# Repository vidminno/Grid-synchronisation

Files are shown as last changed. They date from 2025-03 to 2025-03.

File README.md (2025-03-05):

# Grid synchronisation

This repository contains an easy-to-implement grid synchronisation circuit.

## Content
- **Hardware**: KiCad schematic and layout design for isolated grid frequency acquisition.
- **Software**: Implementation for an STM32 Nucleo H755 for grid synchronisation.

## Functionality
The circuit uses opto-emulators (ISOM8710) for isolated detection of the mains zero crossing. A microcontroller analyses the signal edges to calculate the mains frequency and phase position.

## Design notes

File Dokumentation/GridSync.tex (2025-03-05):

\documentclass[a4paper,12pt]{article}

% Packages
\usepackage[utf8]{inputenc}  % Special characters
\usepackage{amsmath, amssymb} % Mathematical symbols
\usepackage{graphicx} % Including graphics
\usepackage{caption} % Captions for figures
\usepackage{geometry} % Adjusting page margins
\geometry{a4paper, left=2.5cm, right=2.5cm, top=2.5cm, bottom=2.5cm}

\begin{document}
    
    \title{Grid Synchronisation}
    \author{Simon Peter}
    \date{\today}
    \maketitle
    
\begin{abstract}
Dieses Repository enthält eine einfach zu implementierende Grid-Synchronisationsschaltung.
\end{abstract}

\section{Einleitung}
Das Repository enthält die Hardware, bestehend aus einem KiCad-Schaltplan und einem zugehörigen Layoutentwurf. Außerdem ist die Software für einen STM32 Nucleo H755 enthalten.

\section{Hardware}
Nachfolgend wird eine Schaltung vorgestellt, mit der die Netzfrequenz isoliert abgegriffen und der aktuelle Netzzeitpunkt softwareseitig ermittelt werden kann. Die Schaltung besteht aus zwei Komparatoren, welche die Höhe der Netzspannung vergleichen und so auf den Nulldurchgang schließen. Nachteilig an Komparatoren ist die Notwendigkeit einer Spannungsversorgung. Deshalb werden Opto-Emulatoren vom Typ ISOM8710 verwendet, die sich ähnlich wie Optokoppler verhalten. Opto-Emulatoren haben gegenüber Optokopplern jedoch verbesserte Parameter, wie beispielsweise eine höhere Störfestigkeit gegenüber schnellen Gleichtaktspannungen (engl. \textit{High Common Mode Transient Immunity} CMTI).

\begin{figure}[htb]
    \footnotesize
    \centering
    
    \caption{Isolierte Erfassung des Netznulldurchgangs um die Netzfrequenz sowie softwareseitig den Netzzeitpunk zu ermitteln.}	
    \label{fig:HwGridSync}
\end{figure}

Der erste Opto-Emulator (Abbildung~\ref{fig:HwGridSync} oben) soll schalten, wenn in der positiven Halbwelle die Eingangsspannung $u_\text{in}$ ausreichend hoch ist. In der anderen Halbwelle darf er nicht schalten. Mit einer Z-Diode wird diese Eingangsspannung gebildet. Wird die Z-Diode in Sperrrichtung betrieben, liegt die Zenerspannung ($6,2~\text{V}$) an. In der Halbwelle mit entgegengesetzter Polarität befindet sich die Z-Diode in Durchlassrichtung, weshalb die Eingangsspannung zu gering ist. Somit schaltet der Opto-Emulator kurz nach dem Nulldurchgang zur positiven Halbwelle ein und vor dem Nulldurchgang zur negativen Halbwelle aus. Zu beachten ist, dass der Ausgang des ISOM8710 negiert ist. Der Ausgang ist also im Ruhezustand $1$ ($3,3~\text{V}$).

Die beschriebene Schaltung ist doppelt ausgeführt, wobei die zweite Schaltung die Netzspannung entgegengesetzt aufnimmt. Abbildung~\ref{fig:InGridSync} veranschaulicht die beschriebenen Signalverläufe. Der Mikrocontroller kann die Flanken auswerten, hieraus den Nulldurchgang rekonstruieren und somit die Netzfrequenz berechnen. Durch einen internen Takt können zudem jederzeit die aktuellen Winkelverhältnisse des Netzes rekonstruiert werden.

Im Folgenden wird die Schaltung dimensioniert. Es wird ein minimaler Eingangsstrom von $i_\text{in} = 2,5~\text{mA}$ gewählt, der geringfügig über dem empfohlenen minimalen Eingangsstrom von $2~\text{mA}$ liegt. Die Eingangsspannung beträgt hierbei $u_\text{in} = 1,5~\text{V}$. Der minimale Rückwärtsstrom der Z-Diode ist auf $i_\text{D} = 1~\text{mA}$ festgelegt, wobei die Zenerspannung hierbei $u_\text{D} = 6,2~\text{V}$ beträgt. Die minimale netzseitige Eingangsspannung wird auf $U_\text{AC1} = 40~\text{V}$ gesetzt. Mithilfe der Gleichungen~\ref{eq:IsoR1} und~\ref{eq:IsoR2} können nun die erforderlichen Widerstände berechnet werden. Der Kondensator in der Schaltung dient zur Unterdrückung von Störungen.

\begin{align}
    R_1 &= \frac{\widehat{u}_\text{AC12} \cdot \sqrt{2} - u_\text{D}}{i_\text{in} + i_\text{D}} = \frac{40~\text{V} \cdot \sqrt{3} \cdot \sqrt{2} - 6,2~\text{V}}{2,5~\text{mA} + 1~\text{mA}} = 26,22~\text{k}\Omega
    \label{eq:IsoR1} \\
    R_2 &= \frac{u_\text{D} - u_\text{in}}{i_\text{in}} = \frac{6,2~\text{V} - 1,5~\text{V}}{2,5~\text{mA}} = 1,88~\text{k}\Omega
    \label{eq:IsoR2}
\end{align}

\section{Software}
\label{sec:SwGridFrequency}
Zur Bestimmung der Netzfrequenz und der aktuellen Phasenlage muss der Mikrocontroller die Signalflanken von $u_\text{S12\{L,H\}}$ auswerten und in Relation zu einem internen Takt setzen. Wie Abbildung~\ref{fig:InGridSync} zeigt, finden Nulldurchgänge zwischen folgenden Flanken statt.
\begin{itemize}
    \item Nulldurchgang der Eingangsspannung in Richtung der positiven Polarität:\\
    $-$ Positive Flanke von $u_\text{S12L}$ gefolgt von negativer Flanke von $u_\text{S12H}$
    \item Nulldurchgang der Eingangsspannung in Richtung der negativen Polarität:\\
    $-$ Positive Flanke von $u_\text{S12H}$ gefolgt von negativer Flanke von $u_\text{S12L}$
\end{itemize}

Die Detektion der Flanken erfolgt über die Input-Capture-Einheit eines Timers des Mikrocontrollers. Der Timer zählt in der Betriebsart Upcounting. Die Input-Capture-Einheit ermöglicht bei externen Signalflanken die Zwischenspeicherung des aktuellen Timer-Wertes. Beide Signalleitungen triggern jeweils einen Kanal der Input-Capture-Einheit.

\section{Inbetriebnahme}
In diesem Kapitel werden die Signalverläufe der Phasenerkennungsschaltung und die Betriebseigenschaften anhand der Abbildung~\ref{fig:InGridSync} erläutert. Obwohl die Schaltung für $U_\text{AC1} = 40~\text{V}$ dimensioniert wurde, funktioniert sie bereits bei etwa $U_\text{AC1} = 12~\text{V}$. Ohne Anpassung des Vorwiderstandes der Z-Diode wird somit ein großer Spannungsbereich abgedeckt. Die Schaltung ist zwischen $\text{L1}$ und $\text{L2}$ angeschlossen, softwareseitig können daraus jedoch sämtliche Winkelbeziehungen (z.B. zwischen $\text{L1}$ und $\text{N}$) berechnet werden. $u_\text{12\{L,H\}}$ sind die Ausgangssignale der Opto-Emulatoren, welche vom Mikrocontroller für die Nulldurchgangsrekonstruktion ausgewertet werden. $u_\text{t}$ ist ein Testausgangspin des Mikrocontrollers zur Überprüfung der Phasenerkennung. Er wird während der positiven Halbwelle auf $1$ und bei der negativen Halbwelle auf $0$ geschaltet. 

Aufgrund der Hysterese der Opto-Emulatoren stellt sich ein konstanter Winkelfehler von $5$ Grad ein. Dies ist in Abbildung~\ref{fig:InGridSync} ersichtlich, da die steigende Flanke von  $u_\text{12L}$ sowie die fallende Flanke von $u_\text{12H}$ nicht symmetrisch um den Zeitpunkt $t~=~0$ liegen. Dies wird softwareseitig kompensiert, wodurch der Winkelfehler auf unter $1$ Grad verbessert wird. Dies sind in Anbetracht des einfachen Schaltungsaufbaus gute Ergebnisse.

\begin{figure}[ht]
    \footnotesize
    \centering
    
    \caption{Signalverläufe der Phasenerkennungsschaltung bei $f~=~55~\text{Hz}$. Durch die Auswertung der Ausgangssignale $u_\text{12\{L,H\}}$ der Opto-Emulatoren kann der Mikrocontroller den Nulldurchgang exakt vorhersagen (siehe Testausgangssignal $u_\text{t}$).}	
    \label{fig:InGridSync}
\end{figure}

\end{document}

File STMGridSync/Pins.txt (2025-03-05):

---------------------------------------------------------------------
Pin-Belegung
---------------------------------------------------------------------
Pin  |  Funktion  | Status | Beschreibung
---------------------------------------------------------------------

PB0     Nucleo LD1  Use
PE1     Nucleo LD2  Use
PB14    Nucleo LD3  Use
PC13    Nucleo BTN  Use

PE5     TIM15_CH1   Use      Input capture (5V tolerant)
PE6     TIM15_CH2   Use      Input capture (5V tolerant)

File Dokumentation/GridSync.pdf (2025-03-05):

## Grid Synchronisation

### Simon Peter

### March 5, 2025

Abstract

Dieses Repository enthält eine einfach zu implementierende Grid-Synchronisationsschaltung.

### 1 Einleitung

Das Repository enthält die Hardware, bestehend aus einem KiCad-Schaltplan und einem zugehörigen Layoutentwurf. Außerdem ist die Software für einen STM32 Nucleo H755 enthalten.

### 2 Hardware

Nachfolgend wird eine Schaltung vorgestellt, mit der die Netzfrequenz isoliert abgegriffen und der aktuelle Netzzeitpunkt softwareseitig ermittelt werden kann. Die Schaltung besteht aus zwei Komparatoren, welche die Höhe der Netzspannung vergleichen und so auf den Nulldurchgang schließen. Nachteilig an Komparatoren ist die Notwendigkeit einer Spannungsversorgung. Deshalb werden Opto-Emulatoren vom Typ ISOM8710 verwendet, die sich ähnlich wie Optokoppler verhalten. Opto-Emulatoren haben gegenüber Optokopplern jedoch verbesserte Parameter, wie beispielsweise eine höhere Störfestigkeit gegenüber schnellen Gleichtaktspannungen (engl. High Common Mode Transient Immunity CMTI).
Der erste Opto-Emulator (Abbildung 1 oben) soll schalten, wenn in der positiven Halbwelle die Eingangsspannung uin ausreichend hoch ist. In der anderen Halbwelle darf er nicht schalten. Mit einer Z-Diode wird diese Eingangsspannung gebildet. Wird die Z-Diode in Sperrrichtung betrieben, liegt die Zenerspannung (6, 2 V) an. In der Halbwelle mit entgegengesetzter Polarität befindet sich die Z-Diode in Durchlassrichtung, weshalb die Eingangsspannung zu gering ist. Somit schaltet der Opto-Emulator kurz nach dem Nulldurchgang zur positiven Halbwelle ein und vor dem Nulldurchgang zur negativen Halbwelle aus. Zu beachten ist, dass der Ausgang des ISOM8710 negiert ist. Der Ausgang ist also im Ruhezustand 1 (3, 3 V).
Die beschriebene Schaltung ist doppelt ausgeführt, wobei die zweite Schaltung die Netzspannung entgegengesetzt aufnimmt. Abbildung 2 veranschaulicht die beschriebenen Signalverläufe. Der Mikrocontroller kann die Flanken auswerten, hieraus den Nulldurchgang rekonstruieren und somit die Netzfrequenz berechnen. Durch einen internen Takt können zudem jederzeit die aktuellen Winkelverhältnisse des Netzes rekonstruiert werden. Im Folgenden wird die Schaltung dimensioniert. Es wird ein minimaler Eingangsstrom von iin = 2, 5 mA gewählt, der geringfügig über dem empfohlenen minimalen Eingangsstrom

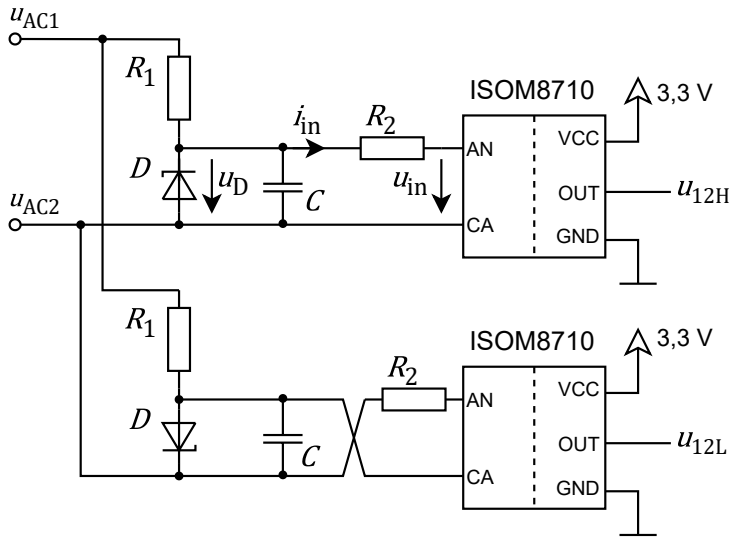
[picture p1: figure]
ISOM8710; VCC; OUT; GND; uAC1; uAC2; uin

Figure 1: Isolierte Erfassung des Netznulldurchgangs um die Netzfrequenz sowie softwareseitig den Netzzeitpunk zu ermitteln.

von 2 mA liegt. Die Eingangsspannung beträgt hierbei uin = 1, 5 V. Der minimale Rückwärtsstrom der Z-Diode ist auf iD = 1 mA festgelegt, wobei die Zenerspannung hierbei uD = 6, 2 V beträgt. Die minimale netzseitige Eingangsspannung wird auf UAC1 = 40 V gesetzt. Mithilfe der Gleichungen 1 und 2 können nun die erforderlichen Widerstände berechnet werden. Der Kondensator in der Schaltung dient zur Unterdrückung von Störungen.

R1 =

ubAC12 ·

√
2 − uD
iin + iD

=

40 V ·

√
3 ·

√
2 − 6, 2 V
2, 5 mA + 1 mA | = 26, 22 kΩ | (1)

R2 =

uD − uin

iin

=

6, 2 V − 1, 5 V
2, 5 mA | = 1, 88 kΩ | (2)

### 3 Software

Zur Bestimmung der Netzfrequenz und der aktuellen Phasenlage muss der Mikrocontroller die Signalflanken von uS12{L,H} auswerten und in Relation zu einem internen Takt setzen. Wie Abbildung 2 zeigt, finden Nulldurchgänge zwischen folgenden Flanken statt.

- Nulldurchgang der Eingangsspannung in Richtung der positiven Polarität:
− Positive Flanke von uS12L gefolgt von negativer Flanke von uS12H
- Nulldurchgang der Eingangsspannung in Richtung der negativen Polarität:
− Positive Flanke von uS12H gefolgt von negativer Flanke von uS12L

Die Detektion der Flanken erfolgt über die Input-Capture-Einheit eines Timers des Mikrocontrollers. Der Timer zählt in der Betriebsart Upcounting. Die Input-Capture-Einheit ermöglicht bei externen Signalflanken die Zwischenspeicherung des aktuellen Timer-Wertes. Beide Signalleitungen triggern jeweils einen Kanal der Input-Capture-Einheit.

### 4 Inbetriebnahme

In diesem Kapitel werden die Signalverläufe der Phasenerkennungsschaltung und die Betriebseigenschaften anhand der Abbildung 2 erläutert. Obwohl die Schaltung für UAC1 = 40 V dimensioniert wurde, funktioniert sie bereits bei etwa UAC1 = 12 V. Ohne Anpassung des Vorwiderstandes der Z-Diode wird somit ein großer Spannungsbereich abgedeckt. Die Schaltung ist zwischen L1 und L2 angeschlossen, softwareseitig können daraus jedoch sämtliche Winkelbeziehungen (z.B. zwischen L1 und N) berechnet werden. u12{L,H} sind die Ausgangssignale der Opto-Emulatoren, welche vom Mikrocontroller für die Nulldurchgangsrekonstruktion ausgewertet werden. ut

ist ein Testausgangspin des Mikrocontrollers zur Uberprüfung der Phasenerkennung. Er wird während der positiven Halbwelle auf 1 ¨ und bei der negativen Halbwelle auf 0 geschaltet.
Aufgrund der Hysterese der Opto-Emulatoren stellt sich ein konstanter Winkelfehler von 5 Grad ein. Dies ist in Abbildung 2 ersichtlich, da die steigende Flanke von u12L sowie die fallende Flanke von u12H nicht symmetrisch um den Zeitpunkt t = 0 liegen. Dies wird softwareseitig kompensiert, wodurch der Winkelfehler auf unter 1 Grad verbessert wird. Dies sind in Anbetracht des einfachen Schaltungsaufbaus gute Ergebnisse.

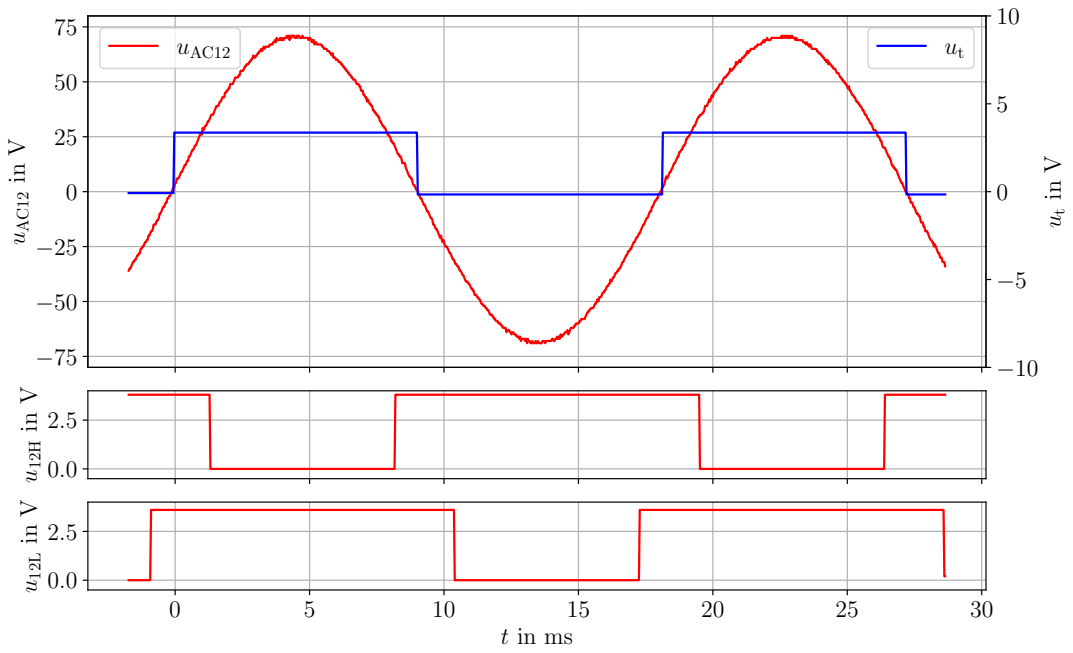
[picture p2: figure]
uAC12 in V; uAC12

Figure 2: Signalverläufe der Phasenerkennungsschaltung bei f = 55 Hz. Durch die Auswertung der Ausgangssignale u12{L,H} der Opto-Emulatoren kann der Mikrocontroller den Nulldurchgang exakt vorhersagen (siehe Testausgangssignal ut).

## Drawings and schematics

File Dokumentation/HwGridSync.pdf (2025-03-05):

## ISOM8710

3,3 V

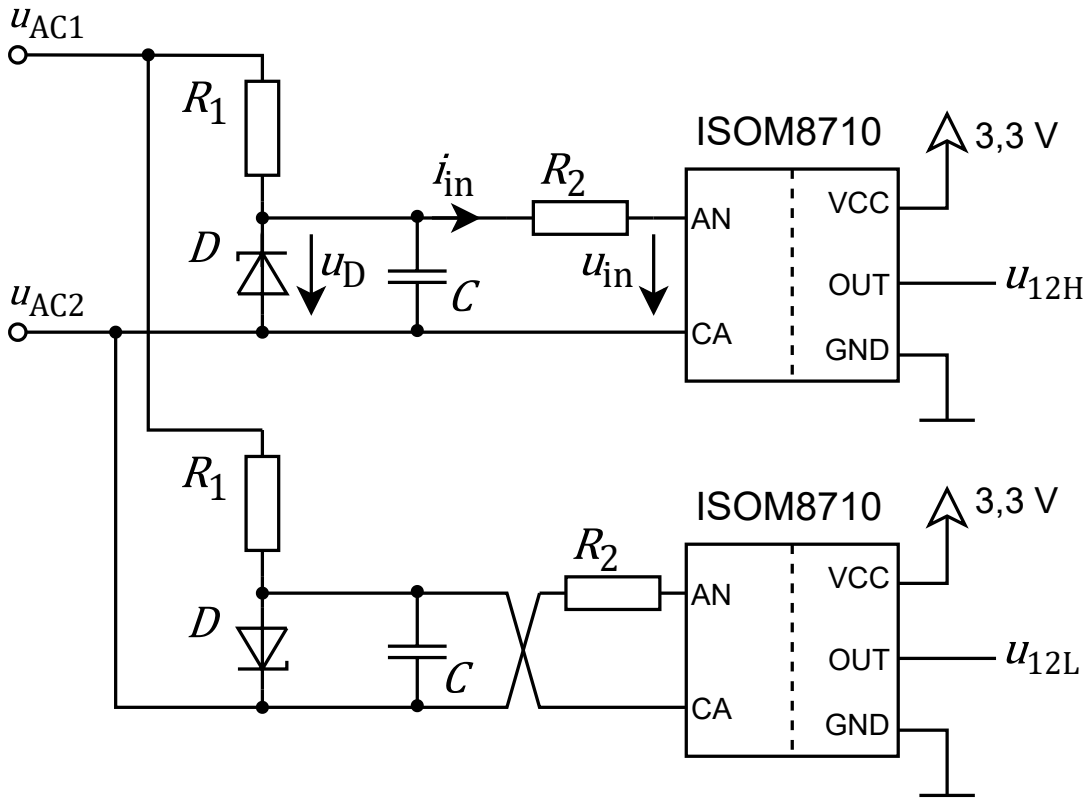
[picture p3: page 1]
VCC; OUT; GND; uAC1 uAC2; ISOM8710

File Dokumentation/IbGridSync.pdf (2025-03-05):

−10 −5 05

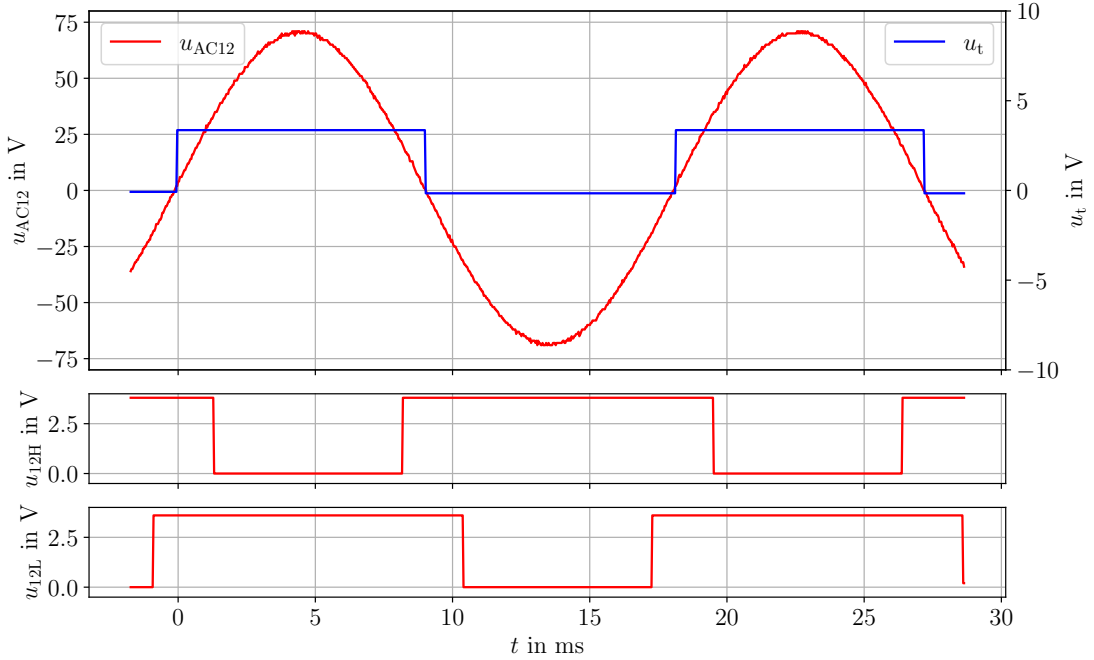
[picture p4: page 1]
uAC12 in V; uAC12

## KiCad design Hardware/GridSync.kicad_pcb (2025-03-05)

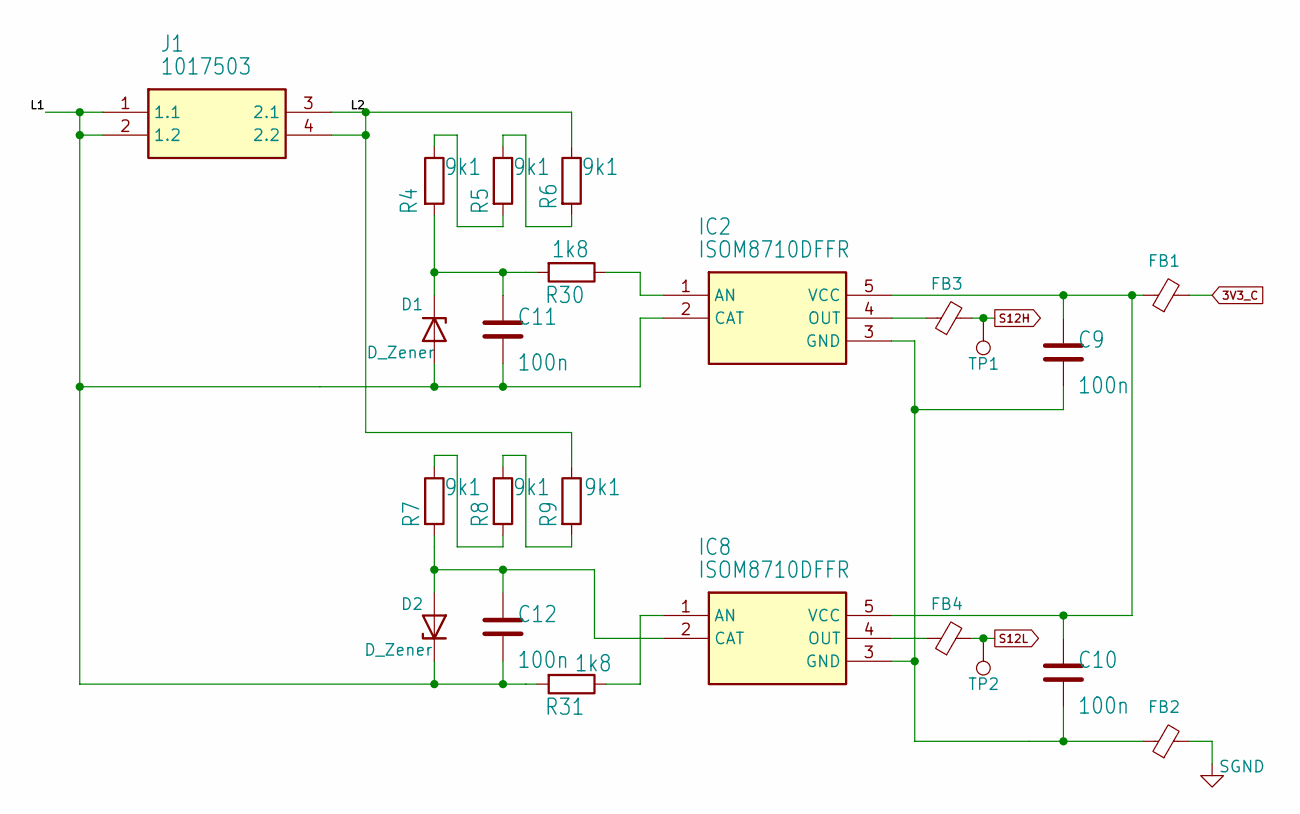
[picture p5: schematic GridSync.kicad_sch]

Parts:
C9, C10, C11, C12: 100n; C_0805_2012Metric_Pad1.18x1.45mm_HandSolder
D1, D2: D_Zener; D_SOD-323_HandSoldering
FB1, FB2, FB3, FB4: L_0805_2012Metric_Pad1.15x1.40mm_HandSolder
IC2, IC8: ISOM8710DFFR; Mouser Part Number 595-ISOM8710DFFR
J1: 1017503; Mouser Part Number 651-1017503
R4, R5, R6, R7, R8, R9: 9k1; R_1206_3216Metric_Pad1.30x1.75mm_HandSolder
R30, R31: 1k8; R_0805_2012Metric_Pad1.20x1.40mm_HandSolder
TP1, TP2: TestPoint; TestPoint_THTPad_D2.0mm_Drill1.0mm

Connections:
3V3_C: FB1.2
/L1: C11.2, C12.2, D1.2 (A), D2.1 (K), IC2.2 (CAT), J1.1 (1.1), J1.2 (1.2), R31.2
/L2: J1.3 (2.1), J1.4 (2.2), R6.1, R9.1
unnamed: C11.1, D1.1 (K), R4.2, R30.2
unnamed: C12.1, D2.2 (A), IC8.2 (CAT), R7.2
unnamed: IC2.1 (AN), R30.1
unnamed: C9.2, C10.2, FB2.1, IC2.3 (GND), IC8.3 (GND)
unnamed: FB3.1, IC2.4 (OUT)
unnamed: C9.1, C10.1, FB1.1, IC2.5 (VCC), IC8.5 (VCC)
unnamed: IC8.1 (AN), R31.1
unnamed: FB4.1, IC8.4 (OUT)
unnamed: R4.1, R5.2
unnamed: R5.1, R6.2
unnamed: R7.1, R8.2
unnamed: R8.1, R9.2
S12H: FB3.2, TP1.1
S12L: FB4.2, TP2.1
SGND: FB2.2

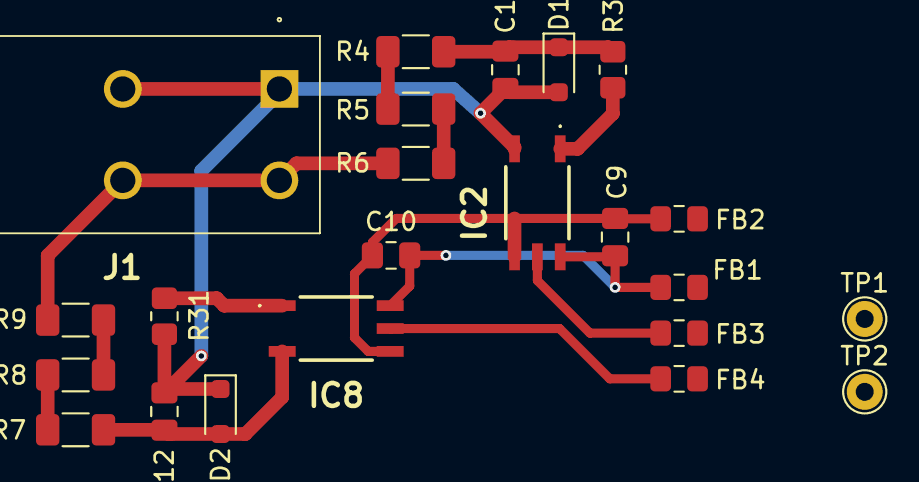
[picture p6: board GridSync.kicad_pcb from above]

Board: 2 copper layers, 23 parts (0 on the bottom side), 16 nets.

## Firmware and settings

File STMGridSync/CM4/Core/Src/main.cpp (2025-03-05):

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
/* Includes ------------------------------------------------------------------*/
#include "main.h"

/* USER CODE BEGIN Includes */
#include "grid_frequency.h"
#include "stm32h7xx_it.h"

/* USER CODE END Includes */

/* USER CODE BEGIN PD */

#ifndef HSEM_ID_0
#define HSEM_ID_0 (0U) /* HW semaphore 0*/
#endif

/* USER CODE END PD */


static void MX_GPIO_Init(void);
/**
  * @brief  The application entry point.
  * @retval int
  */
int main(void)
{

/* USER CODE BEGIN Boot_Mode_Sequence_1 */
  /*HW semaphore Clock enable*/
  __HAL_RCC_HSEM_CLK_ENABLE();
  /* Activate HSEM notification for Cortex-M4*/
  HAL_HSEM_ActivateNotification(__HAL_HSEM_SEMID_TO_MASK(HSEM_ID_0));
  /*
  Domain D2 goes to STOP mode (Cortex-M4 in deep-sleep) waiting for Cortex-M7 to
  perform system initialization (system clock config, external memory configuration.. )
  */
  HAL_PWREx_ClearPendingEvent();
  HAL_PWREx_EnterSTOPMode(PWR_MAINREGULATOR_ON, PWR_STOPENTRY_WFE, PWR_D2_DOMAIN);
  /* Clear HSEM flag */
  __HAL_HSEM_CLEAR_FLAG(__HAL_HSEM_SEMID_TO_MASK(HSEM_ID_0));

/* USER CODE END Boot_Mode_Sequence_1 */
  /* MCU Configuration--------------------------------------------------------*/

  /* Reset of all peripherals, Initializes the Flash interface and the Systick. */
  HAL_Init();

  /* Initialize all configured peripherals */
  MX_GPIO_Init();
  /* USER CODE BEGIN 2 */

	// ###########################################################################################################################################
	// Activate port and interface clocks
	__HAL_RCC_GPIOA_CLK_ENABLE();
	__HAL_RCC_GPIOB_CLK_ENABLE();
	__HAL_RCC_GPIOC_CLK_ENABLE();
	__HAL_RCC_GPIOD_CLK_ENABLE();
	__HAL_RCC_GPIOE_CLK_ENABLE();

	// ###########################################################################################################################################
	// Initialize Timer and grid frequency detection
	__HAL_RCC_TIM15_CLK_ENABLE();
	GPIO_TypeDef* gridFrequGpios[2]  = {T15CH1_GPIO_Port, nullptr};
	uint32_t gridFrequPins[2]  = {T15CH1_Pin | T15CH2_Pin, 0};
	uint32_t gridFrequPinsAf[2]  = {GPIO_AF4_TIM15, 0};
	GridSyncTim gridSyncTim(TIM15, 180000000UL, &gridFrequGpios[0], gridFrequPins, gridFrequPinsAf);
	gridSyncTimInit(gridSyncTim);

	// ###########################################################################################################################################
  	// Attach event handler for DMA filling and grid frequency detection
  	EventHandler evHandler(10);
	GridSync gridSync(gridSyncTim, 180000000UL);
	EvGridSync evGridSync("Grid synchronisation", gridSync);
  	evHandler.addEvent(&evGridSync);
  	setEvGridSync(&evGridSync);

  /* USER CODE END 2 */

  /* Infinite loop */
  /* USER CODE BEGIN WHILE */
  while (1)
  {
		evHandler.process();

		// Toggle LED during reconstructed zero crossing
		static float dt, phi=-0.523598;
		bool sign =  gridSync.sinGrid(dt, phi) > 0.0f;
		static bool signLast = false;
		if (sign && !signLast)
		HAL_GPIO_WritePin(LD3_GPIO_Port, LD3_Pin, GPIO_PIN_SET);
		else if (!sign && signLast)
		HAL_GPIO_WritePin(LD3_GPIO_Port, LD3_Pin, GPIO_PIN_RESET);
		signLast = sign;

    /* USER CODE END WHILE */

    /* USER CODE BEGIN 3 */
  }
  /* USER CODE END 3 */
}

/**
  * @brief GPIO Initialization Function
  * @param None
  * @retval None
  */
static void MX_GPIO_Init(void)
{
  GPIO_InitTypeDef GPIO_InitStruct = {0};
  /* GPIO Ports Clock Enable */
  __HAL_RCC_GPIOE_CLK_ENABLE();
  __HAL_RCC_GPIOC_CLK_ENABLE();
  __HAL_RCC_GPIOB_CLK_ENABLE();
  __HAL_RCC_GPIOF_CLK_ENABLE();
  __HAL_RCC_GPIOD_CLK_ENABLE();

  /*Configure GPIO pin Output Level */
  HAL_GPIO_WritePin(GPIOB, LD1_Pin|LD3_Pin, GPIO_PIN_RESET);

  /*Configure GPIO pin Output Level */
  HAL_GPIO_WritePin(USB_OTG_FS_PWR_EN_GPIO_Port, USB_OTG_FS_PWR_EN_Pin, GPIO_PIN_RESET);

  /*Configure GPIO pin Output Level */
  HAL_GPIO_WritePin(LD2_GPIO_Port, LD2_Pin, GPIO_PIN_RESET);

  /*Configure GPIO pin : B0_Pin */
  GPIO_InitStruct.Pin = B0_Pin;
  GPIO_InitStruct.Mode = GPIO_MODE_INPUT;
  GPIO_InitStruct.Pull = GPIO_NOPULL;
  HAL_GPIO_Init(B0_GPIO_Port, &GPIO_InitStruct);

  /*Configure GPIO pins : LD1_Pin LD3_Pin */
  GPIO_InitStruct.Pin = LD1_Pin|LD3_Pin;
  GPIO_InitStruct.Mode = GPIO_MODE_OUTPUT_PP;
  GPIO_InitStruct.Pull = GPIO_NOPULL;
  GPIO_InitStruct.Speed = GPIO_SPEED_FREQ_LOW;
  HAL_GPIO_Init(GPIOB, &GPIO_InitStruct);

  /*Configure GPIO pin : PF11 */
  GPIO_InitStruct.Pin = GPIO_PIN_11;
  GPIO_InitStruct.Mode = GPIO_MODE_ANALOG;
  GPIO_InitStruct.Pull = GPIO_NOPULL;
  HAL_GPIO_Init(GPIOF, &GPIO_InitStruct);

  /*Configure GPIO pin : USB_OTG_FS_PWR_EN_Pin */
  GPIO_InitStruct.Pin = USB_OTG_FS_PWR_EN_Pin;
  GPIO_InitStruct.Mode = GPIO_MODE_OUTPUT_PP;
  GPIO_InitStruct.Pull = GPIO_NOPULL;
  GPIO_InitStruct.Speed = GPIO_SPEED_FREQ_LOW;
  HAL_GPIO_Init(USB_OTG_FS_PWR_EN_GPIO_Port, &GPIO_InitStruct);

  /*Configure GPIO pin : LD2_Pin */
  GPIO_InitStruct.Pin = LD2_Pin;
  GPIO_InitStruct.Mode = GPIO_MODE_OUTPUT_PP;
  GPIO_InitStruct.Pull = GPIO_NOPULL;
  GPIO_InitStruct.Speed = GPIO_SPEED_FREQ_LOW;
  HAL_GPIO_Init(LD2_GPIO_Port, &GPIO_InitStruct);

}

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


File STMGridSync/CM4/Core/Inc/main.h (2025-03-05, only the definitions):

#define T15CH1_Pin GPIO_PIN_5
#define T15CH1_GPIO_Port GPIOE
#define T15CH2_Pin GPIO_PIN_6
#define T15CH2_GPIO_Port GPIOE
#define B0_Pin GPIO_PIN_13
#define B0_GPIO_Port GPIOC
#define LD1_Pin GPIO_PIN_0
#define LD1_GPIO_Port GPIOB
#define LD3_Pin GPIO_PIN_14
#define LD3_GPIO_Port GPIOB
#define USB_OTG_FS_PWR_EN_Pin GPIO_PIN_10
#define USB_OTG_FS_PWR_EN_GPIO_Port GPIOD
#define LD2_Pin GPIO_PIN_1
#define LD2_GPIO_Port GPIOE

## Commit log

2025-03-05 SW: Launch M7 first and M4 afterwards
    A manual reset (button) must be performed after the launch
2025-03-05 HW: Add KiCad files
    Add KiCad schematic and board design approach
    [GridSync.kicad_pcb, GridSync.kicad_sch]

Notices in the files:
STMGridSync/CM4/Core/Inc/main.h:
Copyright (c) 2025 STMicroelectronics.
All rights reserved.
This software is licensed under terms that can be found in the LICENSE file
